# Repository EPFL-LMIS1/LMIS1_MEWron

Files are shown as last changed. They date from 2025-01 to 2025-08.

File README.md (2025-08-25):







# LMIS1_MEWron

This respository contains files to recreate the MEWron printers present at LIMS1@EPFL. We do our best to keep an eye on this but refer for questions to the authors of the corresponsing publications. The MEWron is based on the following publication: 

__MEWron: An open-source melt electrowriting platform__

https://doi.org/10.1016/j.addma.2023.103604

Ander Reizabal, Taavet Kangur, Paula G. Saiz, Sönke Menke, Christophe Moser, Jürgen Brugger, Paul D. Dalton, Simon Luposchainsky

Additive Manufacturing, Volume 71, 2023, 103604, ISSN 2214-860.
<br><br>

More information on our work and current developments can be found here: https://go.epfl.ch/mew

If you use the files in this repository for scientific work, we kindly ask you to cite this respository and any publications listed here:
* "MEWron: An open-source melt electrowriting platform" https://doi.org/10.1016/j.addma.2023.103604
* "Performance Comparison of Shape Memory Polymer Structures Printed by Fused Deposition Modeling and Melt Electrowriting" https://doi.org/10.1002/admt.202400466
* "Software image for the assembly of a tubular and syringe based MEWron"  https://doi.org/10.5281/zenodo.16752783

---

### [Flat collector MEWron](https://github.com/EPFL-LMIS1/LMIS1_MEWron/blob/main/Flat%20collector%20MEWron)

Here you can find all information on how to build and set-up your own MEWron with a flat collector. You can also find and image file that you can flash onto a new SD card to see how we set up the printer.

### [Tubular collector MEWron](https://github.com/EPFL-LMIS1/LMIS1_MEWron/blob/main/Tubular%20collector%20MEWron)

Here you can find all information on how to upgrade your existing flat collector MEWron with a tubular collector. You can also find and image file that you can flash onto a new SD card to see how we set up the printer.

### [G-Codes and Code generator](https://github.com/EPFL-LMIS1/LMIS1_MEWron/blob/main/G-Codes)

Here you can find phython scripts to generate your own G-codes as well as some premade ones.

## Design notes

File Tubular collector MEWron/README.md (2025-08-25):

# Tubular collector MEWron

Here you can find the files needed to recreate a tubular collector MEWron printer like the ones present at LIMS1@EPFL. We do our best to keep an eye on this but refer for questions to the authors of the corresponding publications.

Before starting to build a tubular MEWron, please refer to the other sections on building a MEWron with a flat collector.

If you need further help, consider downloading a full software image here: "Software image for the assembly of a tubular and syringe based MEWron"  https://doi.org/10.5281/zenodo.16752783

If you use the files in this repository for scientific work, we kindly ask you to cite this repository and any publications listed here: 

* "Performance Comparison of Shape Memory Polymer Structures Printed by Fused Deposition Modeling and Melt Electrowriting" https://doi.org/10.1002/admt.202400466
* "Addition of a tubular collector to a MEWron melt electrowriting printer" https://dx.doi.org/10.17504/protocols.io.4r3l292z3v1y/v1
* "Software image for the assembly of a tubular and syringe based MEWron"  https://doi.org/10.5281/zenodo.16752783

---
Here you can find all the stl. files that needed to be print in order to build a tubular MEWron. For printing guidelines, please refer to the Voron manual.
Furthermore, you can find a 3D model of the assembled printer in these files.
The tubular printer was developed during a semester project at the Swiss Federal institute of Technology (EPFL), Lausanne. The pdf report can be found in this repository as well as here: https://infoscience.epfl.ch/handle/20.500.14299/241044 

In the model, you can see that the more isolated printbed from the original MEWron paper is being used. In our lab, we decided to use the stock printbed, without issues regarding eclectic arcing.

More information on tubular printers as well as a parts list can be found in the following publication: "Melt Electrowriting of Nylon-12 Microfibers with an Open-Source 3D Printer" https://doi.org/10.1002/marc.202300424

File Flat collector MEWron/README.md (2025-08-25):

# Flat Collector MEWron

Here you can find the files needed to recreate a flat collector MEWron printer like the ones present at LIMS1@EPFL. We do our best to keep an eye on this but refer for questions to the authors of the corresponsing publications.

For an instruction on how to build the MEWron, please see here:
Sönke Menke, Biranche Tandon, Juergen Brugger 2024. "Conversion of a Voron FDM printer to a MEWron melt electrowriting printer." protocols.io
https://dx.doi.org/10.17504/protocols.io.q26g71kk3gwz/v1

If you need further help, consider downloading a full software image here: "Software image for the assembly of a tubular and syringe based MEWron"  https://doi.org/10.5281/zenodo.16752783

If you use the files in this repository for scientific work, we kindly ask you to cite this respository and any publications listed here:
* "MEWron: An open-source melt electrowriting platform" https://doi.org/10.1016/j.addma.2023.103604
* "Conversion of a Voron FDM printer to a MEWron melt electrowriting printer." 
https://dx.doi.org/10.17504/protocols.io.q26g71kk3gwz/v1
* "Software image for the assembly of a tubular and syringe based MEWron"  https://doi.org/10.5281/zenodo.16752783

---
For this conversion, the following other repositories are needed:

https://github.com/Chr157i4n/TMC2209_Raspberry_Pi/tree/main

https://github.com/mewron/mewron (the two files "speed.py" and "speed.sh" in this repository are taken directly from there)

---
For the conversion of a Voron 0.1 or 0.2, please follow the protocol and find the 3D files in this github: https://github.com/mewron/mewron
For the conversion of a Voron Trident, please follow the protocol and find the files in this github.

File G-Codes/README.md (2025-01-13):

# G-Codes and G-code generators

Here you can find some G-codes used by us and generators to recreate these for your systems.

The generator for tubular prints was developed in parts during a semester project by Alessandro Zedgitt (https://infoscience.epfl.ch/handle/20.500.14299/241044).

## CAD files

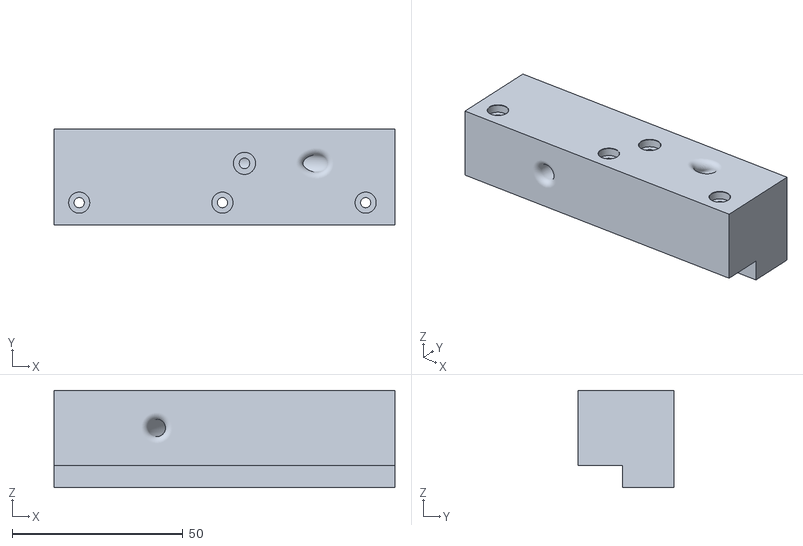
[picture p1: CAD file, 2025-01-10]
Flat collector MEWron/HV cable holder.stl
100.0 x 28.0 x 28.5

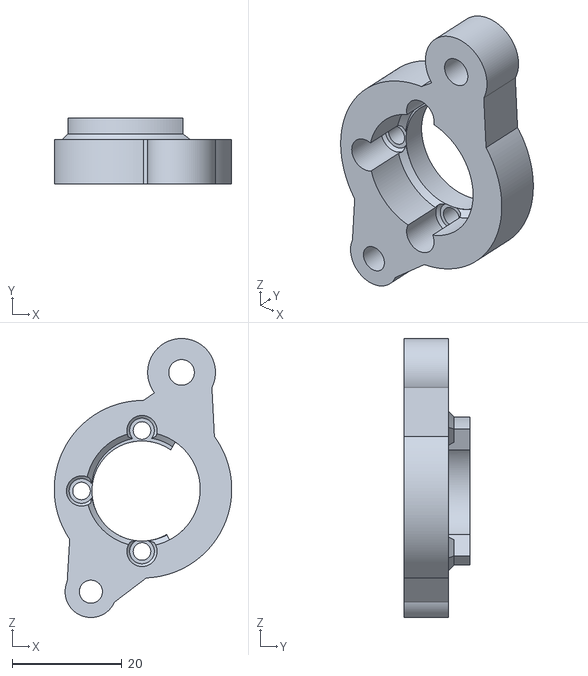
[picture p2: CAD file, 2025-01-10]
Flat collector MEWron/Trident/MotorHolder_Trident.stl
32.3 x 12.0 x 50.8

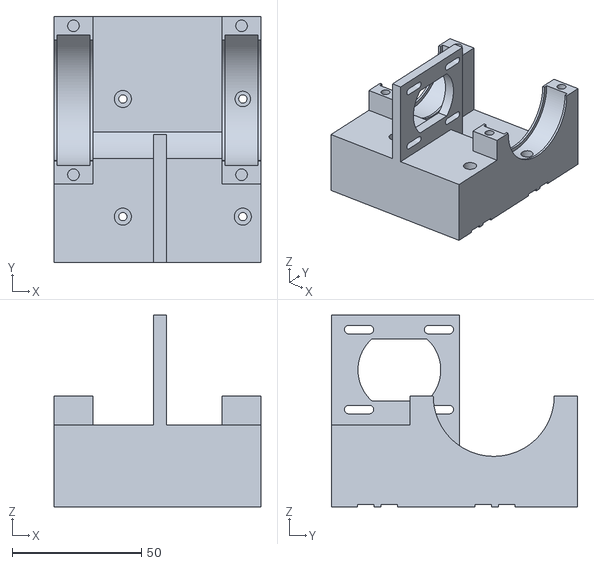
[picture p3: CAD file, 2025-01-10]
Tubular collector MEWron/Mandrel_holder_Lower.stl
80.0 x 95.2 x 74.2

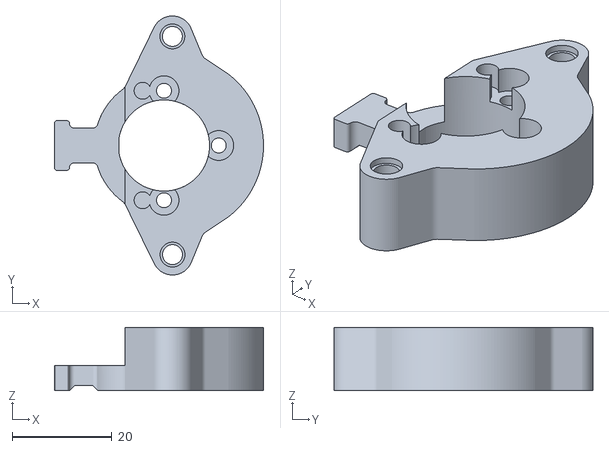
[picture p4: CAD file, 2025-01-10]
Flat collector MEWron/Motor_holder_Voron_0.1.stl
42.0 x 52.0 x 12.7

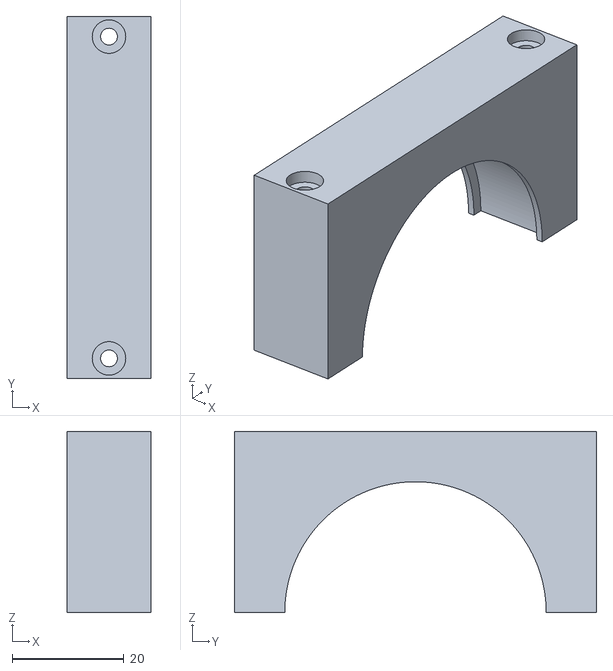
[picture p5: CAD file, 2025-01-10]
Tubular collector MEWron/Mandrel_holder_upper_a.stl
15.0 x 64.8 x 32.4

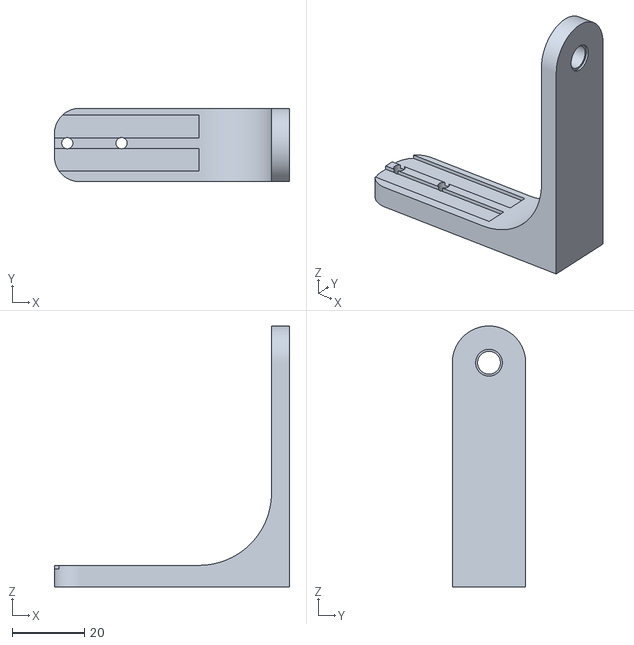
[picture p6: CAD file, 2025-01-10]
Tubular collector MEWron/Mandrel_support_left.stl
65.0 x 20.3 x 72.1

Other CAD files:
Tubular collector MEWron/Mandrel_holder_upper_b.stl

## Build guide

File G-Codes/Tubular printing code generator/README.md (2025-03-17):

# LMIS1_MEWron

This respository contains files to recreate the MEWron printers present at LIMS1@EPFL. We do our best to keep an eye on this but refer for questions to the authors of the corresponsing publications. The MEWron is based on the following publication: 

MEWron: An open-source melt electrowriting platform

https://doi.org/10.1016/j.addma.2023.103604

Ander Reizabal, Taavet Kangur, Paula G. Saiz, Sönke Menke, Christophe Moser, Jürgen Brugger, Paul D. Dalton, Simon Luposchainsky

Additive Manufacturing, Volume 71, 2023, 103604, ISSN 2214-860.

If you use the files in this repository for scientific work, we kindly ask you to cite this respository and any publications listed here:
"MEWron: An open-source melt electrowriting platform" https://doi.org/10.1016/j.addma.2023.103604

# Melt Electrowriting (MEW) G-code generator for tubular collector
This is a guide to use the python G-code generartor for MEWron tubular collector. The tool is based on Voron 0.1 design with the addition of a tubular collector with a Klipper firmware and an Octoprint user interface. 
1. The first step is to clone the python code onto your computer. There are multiple way to do so:
     - **Git Clone**: You should know the basics of git in order to use this. You open a terminal on your computer and run in a specified folder:                                    `git clone https://github.com/EPFL-LMIS1/LMIS1_MEWron.git`
        This will download the code in the folder with the git history. This method allows to edit the software and track the new changes with git as well as keeping the               past changes.
     - **Open with Github Desktop**: This require the app to be installed on your computer. This functions the same way as Git Clone. The main advantage is to have a nice           user interface to observe the results than a computer terminal. 
     - **Download ZIP**: This method downloads all the files of the branch as a zip. The files need to be extracted before use. The main disadvantage of this method is that         you only get the files without the history or the full branches of the project. **Beware currently the main branch only contains ideas of possible upgrades to the              software, the functional code is on the `master` branch**.
   Now that the software is available on your computer, it is ready to use.

2. The next step is to adapt the constants to your system. In order to do so, the `constants.py` file should be opened before starting to edit the values:

| Constant name | description |
| --- | --- |
| FULL_REVOLUTION | The value should correspond to a full revolution of the shaft. This value should never change once measured unless the printer.cfg file is changed. The value can be tested using the terminal inside octoprint: MANUAL_STEPPER=stepper_name MOVE=FULL_REVOLUTION SPEED=speed ACCEL=MANDREL_ACCEL SYNC=0  |
| MANDREL_ACCEL |  This value is the equal to the maximum accelerartion allowed to be applied by the motor to the shaft. The value can be found in the klipper config file on the printer: `printer.cfg`  |
| LAYER_HEIGHT  | When printing multiple layer, the print head should increase the distance to maintain good MEW properties. For prints that are under or equal to 5 layer z offset isn't required. For larger prints, it is recommended to increase the height each layer. **Beware that with a height change to voltage needs to change.** This value should take approximately the value of the diameter of the fiber.  |
| TEMPERATURE  | This value is the melting temperature of the used polymer.  |
| FLOWRATE| This value is a measure how much material is extruded in μg/s. This value is used to compute the wait time in the print.|
|DENSITY | This is density of the material used in g/cm^3|
|OFFSET | The value is a distance to move the print head safely at the end of a print.  |
|FILE_NAME| The name given to the output g-code file takes the following form :FILE_NAME.gcode |
|v_x| The translational speed of the print head along the shaft axis. It is given in mm/min.|
|v_theta_init| In order to addhere the polymer to the mandrel before stabilising, the shaft is rotated a this speed. On our system this value is very low (0.25).|
|R_MANDREL| This is the radius of the shaft that is used inside your system. | 

It doesn't matter what text editor is used a this stage.

3. The third step is to prepare the pattern for the print. The `main.py` file contains the required parameters for the toolpath generation. Each pattern is defined as a repeating unit of a certain length that can be repeated a certain number of times. The number of layers gives the number of stacking fibers, with an z-offset that is given by LAYER_HEIGHT. The distance in between each fiber is given by spacing.

| Constant name | description |
| --- | --- |
|length| This is the length of the repeating unit in mm. **The total length of the pattern is given by length x repetitions.** |
| repetitions | This is the number of repeating patterns to produce a longer sample. |
| layers | This is the number of fiber that are stacked on top of each other.  |
| spacing | This is the distance between the fibers. |
| author | The name of the person who generated the gcode. |
| today | The time stamps at which the gcode file was generated.  |
| pattern | This is the pattern that will be printed. The first option is "tube", the fibre is deposited in a spiral pattern around the shaft, in a stent like pattern. The following layers are printed using the same toolpath then the first layer. The second option is a "pipe" pattern, two types of layers are alterning: straight fibers and tube fibers. The layer is defined as an alternating pair and starts with the straight fibers. The third option is channel, this pattern is the layering of straight fibres that is wrapped by a tube pattern for stability. The last option currently is the custom. The programmer has complete control on the pattern that is produced at the end, from the starting pattern, to the variations in the patterns. **This option should be used by seasoned users.**  |
| starting_position | This is the position at which the fiber should start to adhere to the rod.  |
| stabilisation_pos | This position is the starting position of the stabilisation pattern. This section is very important it enables the fibre to stabilise and be deposited in a uniform way. |
|init_position | This position is where the required pattern is going to print. Each g-code command will be compute in absolute coordinates with respect to this value for the pattern.|
| end_pos | This is the position at which the printhead leaves the shaft to go toward the safety position. |
| safety_pos | This position is defined a safe position to manipulate the shaft without getting burned once the high voltage is removed. This value should change with the user's particular system.|

4. Once the files are edited and save the next step is to compile and run the software to generate the g-code file. The terminal is the easisest method. Open a terminal inside the folder that constains the python code and type : `python main.py` if this should not work try `python3 main.py`. This step assumes that python is already installed, if not the instruction for the installation is available here : `https://www.python.org/downloads/ ` Once the code finished running, a gcode file should appear in the folder. **Beware, if the file name is not changed, then the file is overwritten.**

5. The g-code is finally ready to be uploaded to the print. The file can be dragged and dropped to Octoprint.

6. Before printing, the nozzle should be preheated to the correct temperature. Once the feed rate is set, then the polymer should extrude nicely under the action of the high voltage. Once the polymer consistently flows from the nozzle then the print can be start. From octoprint, just select the file and click on the printer incon to start the print.  

**EXTRA RESOURCES** 
- The basic printer setup is described here as well as an inductation of the meltelectrowriting process. MEWron: An open-source melt electrowriting platform, https://doi.org/10.1016/j.addma.2023.103604
- Voron documentation: https://docs.vorondesign.com/
- Octoprint documentation: https://docs.octoprint.org/en/master/
- Klipper documentation: https://www.klipper3d.org/

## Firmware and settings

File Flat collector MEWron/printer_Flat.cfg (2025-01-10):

# This file contains common pin mappings for the BIGTREETECH SKR mini
# E3 v3.0. To use this config, the firmware should be compiled for the
# STM32G0B1 with a "8KiB bootloader" and USB communication.

# The "make flash" command does not work on the SKR mini E3. Instead,
# after running "make", copy the generated "out/klipper.bin" file to a
# file named "firmware.bin" on an SD card and then restart the SKR
# mini E3 with that SD card.

## Voron Design VORON 0.1 SKR Mini E3 V3 config

## *** THINGS TO CHANGE/CHECK: ***
## MCU path                                                                     [mcu] section
## Z and Extruder motor currents                                                [tmc2209 stepper_*] sections. Uncomment the stepper motor you have
## Full steps per rotation for Extruder                                         [extruder] section
## Thermistor types                                                             [extruder] and [heater_bed] sections - See https://www.klipper3d.org/Config_Reference.html#common-thermistors for common thermistor types
## Extruder motor currents                                                      [extruder] section
## PID tune                                                                     [extruder] and [heater_bed] sections
## Fine tune E steps                                                            [extruder] section
## For more info                                                                check https://docs.vorondesign.com/build/startup/#v0

[mcu]
#####################################################################
# Obtain definition by "ls -l /dev/serial/by-id/"
#####################################################################
serial: /dev/serial/by-id/usb-Klipper_stm32g0b1xx_4A0025000150414235363020-if00

[printer]
kinematics: corexy
max_velocity: 300
max_accel: 3000
max_z_velocity: 15
max_z_accel: 45
square_corner_velocity: 6.0

#[include adxl.cfg] # Comment this out when you disconnect the accelerometer

#####################################################################
#      X/Y Stepper Settings
#####################################################################

[stepper_x]
step_pin: PB13
## Refer to https://docs.vorondesign.com/build/startup/#v0
dir_pin: PB12                                                       # Check motor direction in link above. If inverted, add a ! before PB12
enable_pin: !PB14
rotation_distance: 40
microsteps: 32
full_steps_per_rotation: 200                                        # Set to 400 for 0.9 degree stepper motor, 200 is for 1.8 stepper motors
endstop_pin: ^PC0 
position_endstop: 120
position_max: 120
homing_speed: 50                                                    # Can be increased after initial setup, Max 100
homing_retract_dist: 5
homing_positive_dir: true

[tmc2209 stepper_x]
uart_pin: PC11
tx_pin: PC10
uart_address: 0
interpolate: False
run_current: 0.5
sense_resistor: 0.110
stealthchop_threshold: 0                                            # Set to 999999 to turn stealthchop on, and 0 to use spreadcycle

[stepper_y]
step_pin: PB10
## Refer to https://docs.vorondesign.com/build/startup/#v0
dir_pin: PB2                                                        # Check motor direction in link above. If inverted, add a ! before PB2
enable_pin: !PB11
rotation_distance: 40
microsteps: 32
full_steps_per_rotation: 200                                        # Set to 400 for 0.9 degree stepper motor, 200 is for 1.8 stepper motors
endstop_pin: ^PC1
position_endstop: 120
position_max: 120
homing_speed: 50                                                    # Can be increased after initial setup, Max 100
homing_retract_dist: 5
homing_positive_dir: true

[tmc2209 stepper_y]
uart_pin: PC11
tx_pin: PC10
uart_address: 2
interpolate: False
run_current: 0.5
sense_resistor: 0.110
stealthchop_threshold: 0                                            # Set to 999999 to turn stealthchop on, and 0 to use spreadcycle

#####################################################################
#   Z Stepper Settings
#####################################################################

[stepper_z]
step_pin: PB0
dir_pin: !PC5                                                       # Remove the ! before PC5 if motor direction is inverted.
enable_pin: !PB1
rotation_distance: 8                                                # For T8x8 integrated lead screw
microsteps: 32
endstop_pin: ^PC2
#position_endstop: -0.10
position_max: 120
position_min: -1.5
homing_speed: 10
second_homing_speed: 3.0
homing_retract_dist: 3.0

[tmc2209 stepper_z]
uart_pin: PC11
tx_pin: PC10
uart_address: 1
interpolate: False
## For OMC (StepperOnline) 17LS13-0404E-200G 0.4A 
#run_current: 0.2
## For LDO-42STH25-1004CL200E 1.0A
run_current: 0.37
sense_resistor: 0.110
stealthchop_threshold: 0                                            # Set to 999999 to turn stealthchop on, and 0 to use spreadcycle

#####################################################################
#   Extruder
#####################################################################

[extruder]
step_pin: PB3
dir_pin: PB4                                                        # Add ! if moving opposite direction
enable_pin: !PD1
#full_steps_per_rotation: 200                                       # Set to 200 for LDO 1.8 stepper motor, and set to 400 for OMC(StepperOnline) 0.9 stepper motor
rotation_distance: 22.23                                            # See calibrating rotation_distance on extruders doc
gear_ratio: 50:10                                                   # For Mini Afterburner
microsteps: 32
nozzle_diameter: 0.400
filament_diameter: 1.750
heater_pin: PC8
## Check what thermistor type you have. See https://www.klipper3d.org/Config_Reference.html#common-thermistors for common thermistor types.
## Use "Generic 3950" for NTC 100k 3950 thermistors
sensor_type: ATC Semitec 104NT-4-R025H42G
sensor_pin: PA0
#control: pid                                                        # Do PID calibration after initial checks
#pid_Kp: 28.182
#pid_Ki: 1.978
#pid_Kd: 100.397
min_temp: 0
max_temp: 270
min_extrude_temp: 170
max_extrude_only_distance: 150
max_extrude_cross_section: 0.8
pressure_advance: 0.0                                               # See tuning pressure advance doc
pressure_advance_smooth_time: 0.040

[verify_heater extruder]
max_error: 400
#   The maximum "cumulative temperature error" before raising an
#   error. Smaller values result in stricter checking and larger
#   values allow for more time before an error is reported.
#   Specifically, the temperature is inspected once a second and if it
#   is close to the target temperature then an internal "error
#   counter" is reset; otherwise, if the temperature is below the
#   target range then the counter is increased by the amount the
#   reported temperature differs from that range. Should the counter
#   exceed this "max_error" then an error is raised. The default is
#   120.
check_gain_time:120
#   This controls heater verification during initial heating. Smaller
#   values result in stricter checking and larger values allow for
#   more time before an error is reported. Specifically, during
#   initial heating, as long as the heater increases in temperature
#   within this time frame (specified in seconds) then the internal
#   "error counter" is reset. The default is 20 seconds for extruders
#   and 60 seconds for heater_bed.
#hysteresis: 5
#   The maximum temperature difference (in Celsius) to a target
#   temperature that is considered in range of the target. This
#   controls the max_error range check. It is rare to customize this
#   value. The default is 5.
#heating_gain: 2
#   The minimum temperature (in Celsius) that the heater must increase
#   by during the check_gain_time check. It is rare to customize this
#   value. The default is 2.



[tmc2209 extruder]
uart_pin: PC11
tx_pin: PC10
uart_address: 3
interpolate: False
## For OMC (StepperOnline) 14HR07-1004VRN 1A 0.9
#run_current: 0.5   # for OMC 14HR07-1004VRN rated at 1A
## For LDO LDO 36STH17-1004AHG 1A 1.8 
run_current: 0.3   # for LDO 36STH17-1004AHG
## For LDO LDO 36STH20-1004AHG 1A 1.8 
#run_current: 0.6   # for LDO 36STH20-1004AHG
sense_resistor: 0.110
stealthchop_threshold: 0                                            # Set to 0 for spreadcycle, avoid using stealthchop on extruder

#####################################################################
#   Bed Heater
#####################################################################
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

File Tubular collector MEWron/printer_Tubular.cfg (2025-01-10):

# This file contains common pin mappings for the Fysetc Spider board.
# To use this config, the firmware should be compiled for the STM32F446.
# When calling "menuconfig", enable "extra low-level configuration setup"
# and select the "12MHz crystal" as clock reference.
# For flashing, write the compiled klipper.bin to memory location 0x08000000

# See docs/Config_Reference.md for a description of parameters.


[mcu] #ok
## Obtain definition by "ls -l /dev/serial/by-id/" then unplug to verify

serial: /dev/serial/by-id/usb-Klipper_stm32f446xx_3B003E001451303530323539-if00

[printer] #ok
kinematics: corexy
max_velocity: 200
max_accel: 2000
max_z_velocity: 15
max_z_accel: 45

[thermistor my_thermistor_ATC]
temperature1: 25
resistance1: 100000
temperature2: 136.1
resistance2: 1753
temperature3:304.9
resistance3: 115.6

########################################
# Actuators configuration
########################################

[stepper_x]
step_pin: PE11
dir_pin: !PE10
enable_pin: !PE9
microsteps: 16
rotation_distance: 40
endstop_pin: ^PA1  # PA1 for X-max
position_endstop: 120
position_max: 120
homing_speed: 35

[tmc2209 stepper_x]
uart_pin: PE7
interpolate: False
#uart_address:1
#tx_pin: PE7
run_current: 0.5
hold_current: 0.25
sense_resistor: 0.110
stealthchop_threshold: 0

[stepper_y]
step_pin: PD8
dir_pin: !PB12
enable_pin: !PD9
microsteps: 16
rotation_distance: 40
endstop_pin: ^PA2  # PA2 for Y-max ^PB13
position_endstop: 120
position_max: 120
homing_speed: 35

[tmc2209 stepper_y]
uart_pin: PE15
#uart_address:1
#tx_pin: PE7
run_current: 0.5
hold_current: 0.25
sense_resistor: 0.110
stealthchop_threshold: 0

[stepper_z]
step_pin: PD14
dir_pin: !PD13
enable_pin: !PD15
microsteps: 16
rotation_distance: 8
endstop_pin: PA3  # PA3 for Z-max
#position_endstop: 0
position_max: 50
position_min: -10
homing_speed: 5

[tmc2209 stepper_z]
uart_pin: PD10
run_current: 0.5
hold_current: 0.3
sense_resistor: 0.110
stealthchop_threshold: 500

[extruder]
step_pin: PD5
dir_pin: !PD6
enable_pin: !PD4
microsteps: 16
rotation_distance: 21.9336 
nozzle_diameter: 0.400
filament_diameter: 1.750
heater_pin: PC8
sensor_type: my_thermistor_ATC #reference of the sensor lost so defined
#with a custom sensor callibrated manually
sensor_pin: PB1
#control: pid
#pid_Kp: 22
#pid_Ki: 1.08
#pid_Kd: 114
min_temp: 0
max_temp: 300
min_extrude_temp: 0

[tmc2209 extruder] 
uart_pin: PD7
run_current: 0.5
hold_current: 0.3
sense_resistor: 0.110
stealthchop_threshold: 0

[verify_heater extruder]
max_error: 900 #default 120
check_gain_time:60 #default 20
hysteresis:10 #default 5; taret in range of hysteresis
heating_gain: 2 #default 2; temperature required to gain in the check_error_time


#[stepper_1]
[manual_stepper stepper_1]
step_pin: PE6
dir_pin: !PC13
enable_pin: !PE5
rotation_distance:3#3.12# angle reasoning #16.55649 large gear #1.31749  mandrel distance
microsteps: 64
#https://klipper.discourse.group/t/manual-stepper-problems/412
#velocity:
#   Set the default velocity (in mm/s) for the stepper. This value
#   will be used if a MANUAL_STEPPER command does not specify a SPEED
#   parameter. The default is 5mm/s.
#accel:
#   Set the default acceleration (in mm/s^2) for the stepper. An
#   acceleration of zero will result in no acceleration. This value
#   will be used if a MANUAL_STEPPER command does not specify an ACCEL
#   parameter. The default is zero.
#endstop_pin:
#   Endstop switch detection pin. If specified, then one may perform
#   "homing moves" by adding a STOP_ON_ENDSTOP parameter to
#   MANUAL_STEPPER movement commands.

#[tmc2209 stepper_1]
[tmc2209 manual_stepper stepper_1]
uart_pin: PC14
interpolate: False
run_current: 0.5
hold_current: 0.3
sense_resistor: 0.110
stealthchop_threshold: 500

[heater_bed]
heater_pin: PB4
sensor_type: EPCOS 100K B57560G104F
sensor_pin: PC3
#control: watermark
min_temp: 0
max_temp: 130

#fan for printed model FAN0
[heater_fan extruder_fan]
pin: PB2
max_power: 1.0
kick_start_time: 0.5
off_below: 0.13
cycle_time: 0.010

#shutdown_speed:
#hardware_pwm:

#enable_pin:
#   See the "fan" section for a description of the above parameters.
heater: extruder
#   Name of the config section defining the heater that this fan is
#   associated with. If a comma separated list of heater names is
#   provided here, then the fan will be enabled when any of the given
#   heaters are enabled. The default is "extruder".
heater_temp: 40.0
#   A temperature (in Celsius) that the heater must drop below before
#   the fan is disabled. The default is 50 Celsius.
fan_speed: 0.8
#   The fan speed (expressed as a value from 0.0 to 1.0) that the fan
#   will be set to when its associated heater is enabled. The default
#   is 1.0

[bed_screws] #ok
screw1: 60, 5
screw2: 115, 115
screw3: 5, 115

#####################################################################
#   Homing and Gantry Adjustment Routines
#####################################################################

[safe_z_home]
home_xy_position: 19,43
speed: 50.0
z_hop: 5

#####################################################################
# LED Control
#####################################################################

[neopixel my_neopixel] #to test
pin: PD3
#   The pin connected to the neopixel. This parameter must be
#   provided.
chain_count: 8
#   The number of Neopixel chips that are "daisy chained" to the
#   provided pin. The default is 1 (which indicates only a single
#   Neopixel is connected to the pin).
color_order: GRB
#   Set the pixel order required by the LED hardware. Options are GRB,
#   RGB, GRBW, or RGBW. The default is GRB.
initial_RED: 0
initial_GREEN: 0.7
initial_BLUE: 0.7
#initial_WHITE: 0.0
#   Sets the initial LED color of the Neopixel. Each value should be
#   between 0.0 and 1.0. The WHITE option is only available on RGBW
#   LEDs. The default for each color is 0.

#fan for printed model FAN3
[heater_fan led_fan]
pin: PB7
max_power: 1.0
kick_start_time: 0.5
off_below: 0.13
cycle_time: 0.010
#shutdown_speed:
#hardware_pwm:
#enable_pin:
#   See the "fan" section for a description of the above parameters.
heater: extruder
#   Name of the config section defining the heater that this fan is
#   associated with. If a comma separated list of heater names is
#   provided here, then the fan will be enabled when any of the given
#   heaters are enabled. The default is "extruder".
heater_temp: 0.0
#   A temperature (in Celsius) that the heater must drop below before
#   the fan is disabled. The default is 50 Celsius.
fan_speed: 0.8
#   The fan speed (expressed as a value from 0.0 to 1.0) that the fan
#   will be set to when its associated heater is enabled. The default
#   is 1.0




########################################
# EXP1 / EXP2 (display) pins
########################################

[board_pins]
aliases:
    # EXP2 header
    EXP1_10=<5V>, EXP1_9=<GND>,
    EXP1_8=PD1,   EXP1_7=PD0,
    EXP1_6=PC12,  EXP1_5=PC10,     # Slot in the socket on the other side
    EXP1_4=PD2,   EXP1_3=PC11,
    EXP1_2=PA8,   EXP1_1=PC9,

    # EXP1 header
    EXP2_10=<5V>, EXP2_9=<GND>,
    EXP2_8=<RST>, EXP2_7=PB10,
    EXP2_6=PA7,   EXP2_5=PC7,       # Slot in the socket on the other side
    EXP2_4=PA4,   EXP2_3=PC6,
    EXP2_2=PA5,   EXP2_1=PA6

# See the sample-lcd.cfg file for definitions of common LCD displays.

########################################
# G-CODE specifics
########################################

[gcode_macro PRINT_START]
#   Use PRINT_START for the slicer starting script - please customize for your slicer of choice
gcode:
    G28                            ; home all axes
    G1 Z20 F3000                   ; move nozzle away from bed
    M190 S{BED} ; set bed temperature and wait for it to be reached
    M109 S{EXTRUDER}
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

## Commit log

2025-01-10 Upload of 3D files
    The .STL files for the tubular MEWron as well as 3D model have been uploaded.
    [HV cable holder.stl, Mandrel_holder_Lower.stl, Mandrel_holder_upper_a.stl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]
2025-01-10 Upload of 3D files
    [MotorHolder_Trident.stl]
2025-01-10 Updated files
    [printer_Flat.cfg, printer_Tubular.cfg]

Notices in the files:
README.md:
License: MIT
